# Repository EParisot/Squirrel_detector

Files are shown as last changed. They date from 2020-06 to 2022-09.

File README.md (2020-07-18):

# SQuareRooT Project
#### Capture wildlife from your garden !

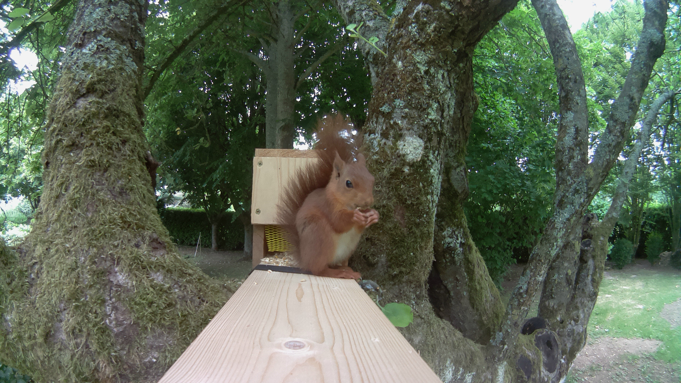
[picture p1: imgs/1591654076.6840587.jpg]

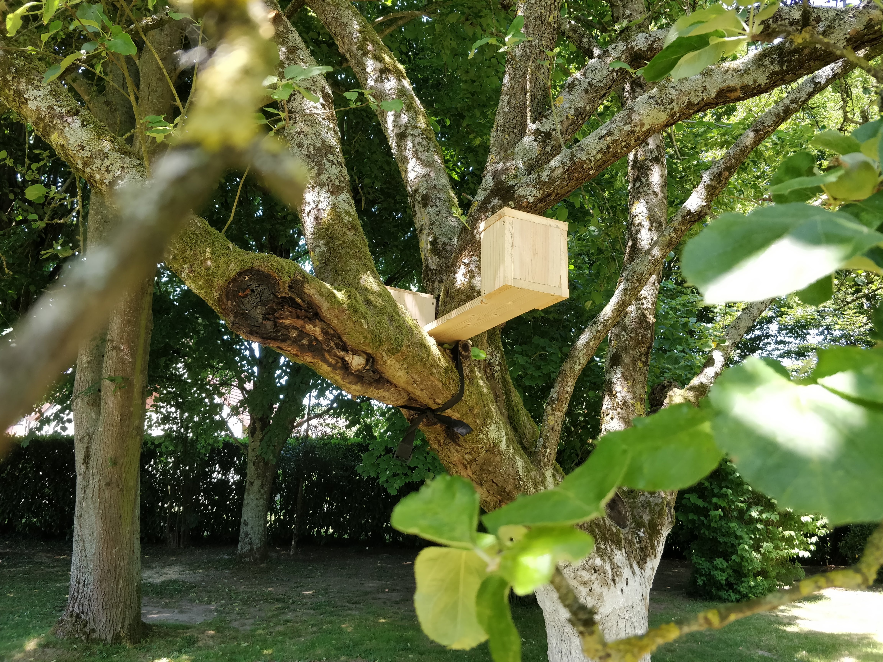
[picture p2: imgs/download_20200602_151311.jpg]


#### More pictures [HERE](https://photos.app.goo.gl/eW7Maa1WmrSnC65B8)

## Material:
* RaspberryPi + SD card : [Shop](https://www.amazon.fr/Raspberry-Pi-3-Mod%C3%A8le-B-Carte-m%C3%A8re/dp/B07BDR5PDW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)
(any RPi model will fit, maybe avoid using a RPi4 (overkill + heat))
* Camera : [Shop](https://www.amazon.fr/Raspberry-160%C2%B0Fisheye-Camera-Longruner-Adjustable-Focus/dp/B074W6TPHF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)
* ToF distance sensor : [Shop](https://www.amazon.fr/gp/product/B07RWT9D5Z/ref=ppx_yo_dt_b_asin_title_o07_s00?ie=UTF8&psc=1)
* Battery pack : [Shop](https://www.amazon.fr/gp/product/B07HK5VGB6/ref=ppx_yo_dt_b_asin_title_o00_s00?ie=UTF8&psc=1)
* Button [Shop](https://www.amazon.fr/AZDelivery-Interrupteur-capteur-dinterrupteur-Arduino/dp/B089QK4XLR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 )
* Light sensor [Shop](https://www.amazon.fr/Photor%C3%A9sistances-GL5539-30K-90K-d%C3%A9pendant-lumi%C3%A8re/dp/B01EZZMLOI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)
* Jumper cables, 1 Capacitor (1microf), 1 led, 1 resistor (330 ohms)

# Instructions:

Based on Raspberry Pi Zero W
Raspberry Pi OS (32-bit) Lite
Minimal image based on Debian Buster
Version:May 2020

### Wire Camera, distance sensor, button, led, everything !

scheme to come...

### Clone the repo on the RPi and install
```
sudo apt-get install git
git clone https://github.com/EParisot/Squirrel_detector.git ~/Squirrel_detector
cd ~/Squirrel_detector
sudo ./install.sh
```
(You will be asked for some interractions while setting wifi... stay focused !)

### Reboot, find a great spot and ... enjoy the show ! 

Everything is made to save up battery life: WIFI stay shutted down until you press the button (no picture can be taken during this time), HDMI is stopped on boot.

A camera test shot is made on start, everything is logged in activity.log file.

If the brightness is not sufficient, no sensor will be triggered for 10 min to avoid black images (and prevent useless power consumption)

A compagnon App is also in progress and will allow user to download images from the device. Start App, press the button and download your pictures on the phone.

## Usefull commands:
Start the STA (wifi client) mode :
```
sudo systemctl start wpa_supplicant@wlan0.service
```
Start the AP (wifi server) mode :
```
sudo systemctl start wpa_supplicant@ap0.service
```
Restart HDMI port :
```
sudo /usr/bin/tvservice -p
(-o to stop)
```

## Licensing
This project is under MIT license which means you can share, use, modify it if you cite the author (me)... Thanks !

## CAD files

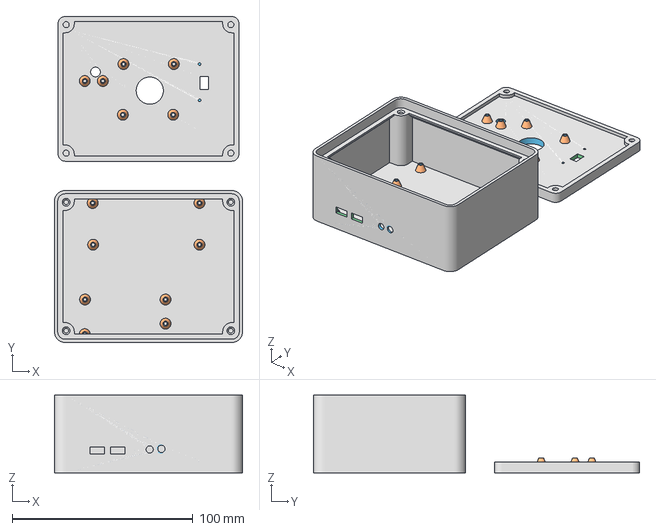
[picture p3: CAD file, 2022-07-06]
3Dprints/project_box_full.3mf
104.0 x 180.1 x 43.0 mm

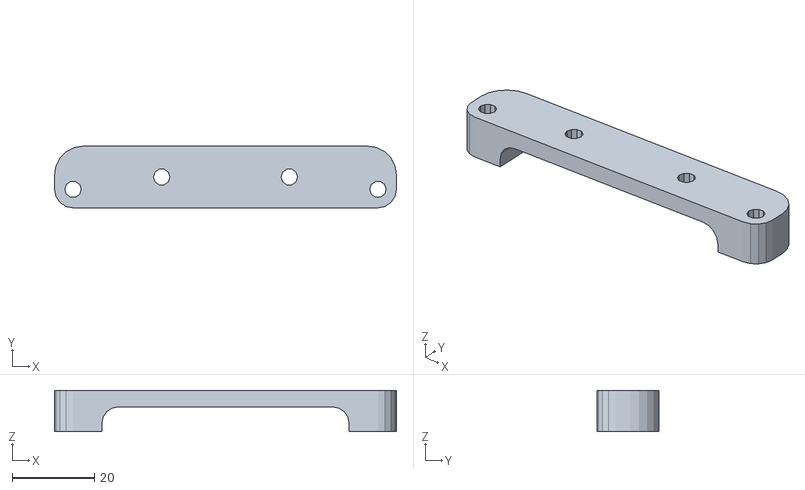
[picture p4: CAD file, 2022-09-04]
3Dprints/Porte_plaque_aimant_V2.stl
83.0 x 15.0 x 10.0

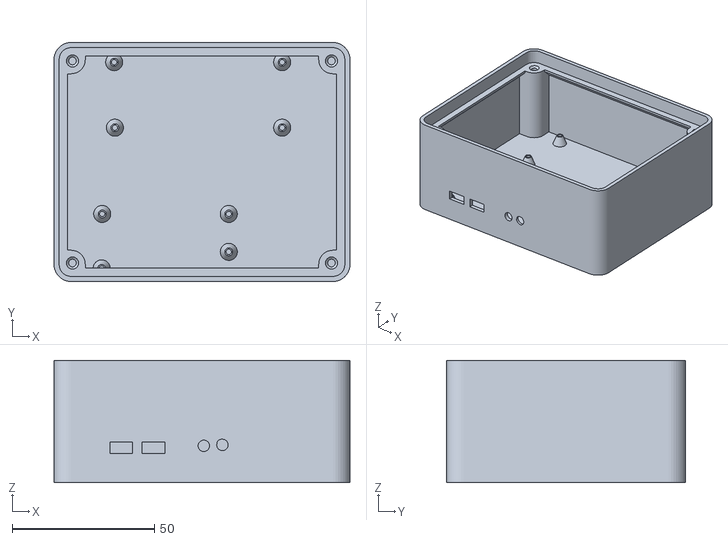
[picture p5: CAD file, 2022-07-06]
3Dprints/project_box_bottom.stl
104.0 x 84.0 x 43.0

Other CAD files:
3Dprints/project_box_full.stl

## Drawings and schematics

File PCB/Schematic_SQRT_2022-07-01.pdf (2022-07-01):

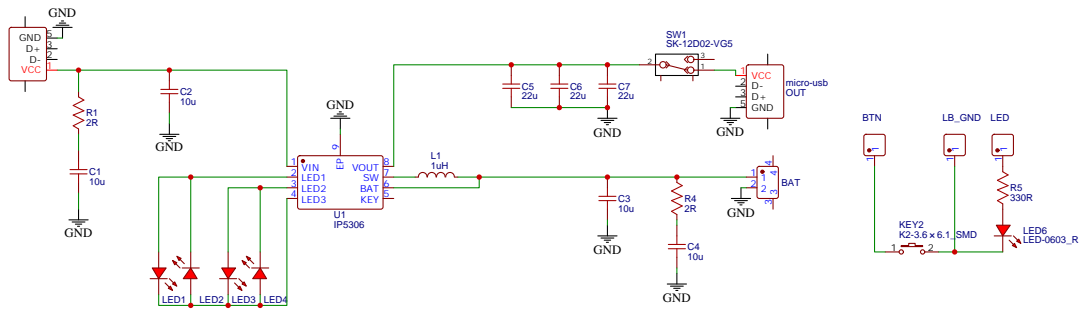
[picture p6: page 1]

Drawn By: parisot.eric.mail

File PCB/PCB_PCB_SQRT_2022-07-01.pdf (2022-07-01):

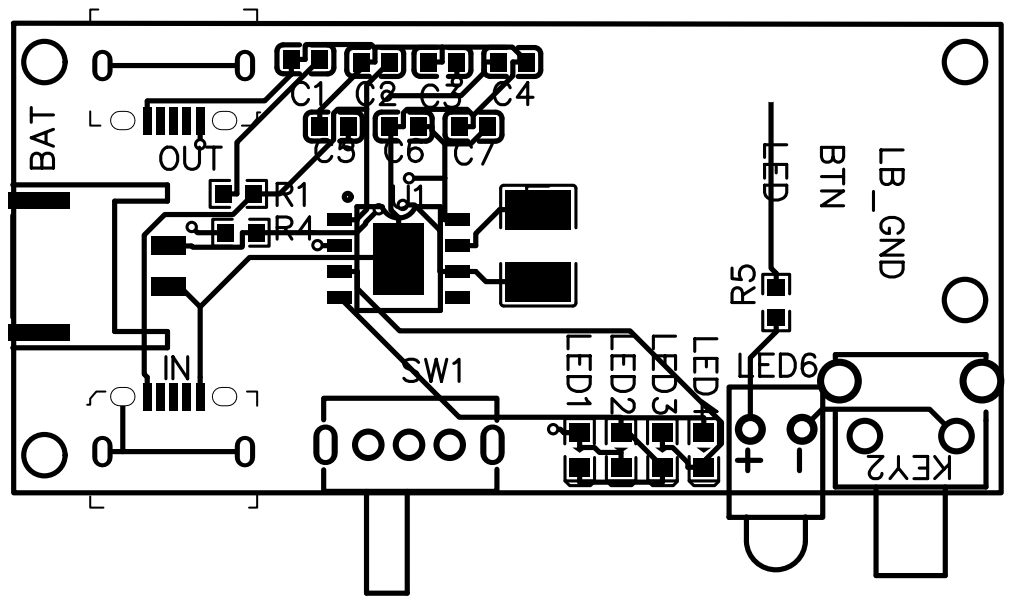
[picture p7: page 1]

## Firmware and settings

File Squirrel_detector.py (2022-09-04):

#! /usr/bin/python3
# coding: utf8
import os
import time
from picamera import PiCamera
import adafruit_vl53l0x
import board
import busio
import RPi.GPIO as GPIO

DEBUG = True

if DEBUG:
	import logging
	from logging.handlers import RotatingFileHandler

	logger = logging.getLogger("main_logger")
	logger.setLevel(logging.DEBUG)
	formatter = logging.Formatter('%(asctime)s :: %(levelname)s :: %(message)s')
	file_handler = RotatingFileHandler('activity.log', 'a', 1000000, 1)
	file_handler.setLevel(logging.DEBUG)
	file_handler.setFormatter(formatter)
	logger.addHandler(file_handler)
	stream_handler = logging.StreamHandler()
	stream_handler.setLevel(logging.DEBUG)
	logger.addHandler(stream_handler)

SRC_FOLDER = "/home/pi/Squirrel_detector/out/"
IMG_EXT = ".png"
WIFI = True
threshold = 45
BTN = 12
LED = 5
LIGHT = 24

def init_sensor():
	global threshold
	try:
		i2c = busio.I2C(board.SCL, board.SDA)
		sensor = adafruit_vl53l0x.VL53L0X(i2c)
		sensor.measurement_timing_budget = 200000
		thrs = []
		i = 5
		while i > 0:
			time.sleep(0.5)
			GPIO.output(LED, GPIO.HIGH)
			time.sleep(0.5)
			GPIO.output(LED, GPIO.LOW)
			distance = sensor.range // 10
			if DEBUG:
				logger.debug("distance = %d" % distance)
			if 0 < distance < 50:
				thrs.append(distance)
			i -= 1
		if len(thrs):
			new_thr = sum(thrs) // len(thrs)
			if 0 < new_thr <= 50:
				threshold = new_thr
		if DEBUG:
			logger.debug("threshold = %d" % threshold)
	except Exception as e:
		if DEBUG:
			logger.info("Error setting dist sensor %s" % str(e))
	return sensor

def init_GPIO():
	GPIO.setup(BTN, GPIO.IN, pull_up_down=GPIO.PUD_UP)
	GPIO.setup(LED, GPIO.OUT)
	GPIO.output(LED, GPIO.LOW)

def light_sensor():
	count = 0
	#Output on the pin for
	GPIO.setup(LIGHT, GPIO.OUT)
	GPIO.output(LIGHT, GPIO.LOW)
	time.sleep(0.1)
	#Change the pin back to input
	GPIO.setup(LIGHT, GPIO.IN)
	#Count until the pin goes high
	while (GPIO.input(LIGHT) == GPIO.LOW) and count <= 10000:
		count += 1
	return count

def clean_all():
	cmd = 'ifconfig wlan0 up'
	os.system(cmd)
	time.sleep(1)
	cmd = "systemctl start wpa_supplicant@ap0.service"
	GPIO.output(LED, GPIO.LOW)
	GPIO.cleanup()

def wifi_switch():
	global start_AP
	if WIFI == False:
		if DEBUG:
			logger.info("Disactivate Wifi AP")
		cmd = "systemctl start wpa_supplicant@wlan0.service"
		os.system(cmd)
		time.sleep(1)
		cmd = 'ifconfig wlan0 down'
		os.system(cmd)
	elif WIFI == True:
		if DEBUG:
			logger.info("Activate Wifi AP")
		cmd = 'ifconfig wlan0 up'
		os.system(cmd)
		time.sleep(1)
		cmd = "systemctl start wpa_supplicant@ap0.service"
		os.system(cmd)
		start_AP = time.time()
	time.sleep(1)

def button_callback(channel):
	if GPIO.input(BTN) == 0:
		global WIFI
		if DEBUG:
			logger.info("Button pushed ! Switching wifi state to %s" % ("OFF" if WIFI else "ON"))
		WIFI = not WIFI
		wifi_switch()

def take_snap():
	with PiCamera(resolution=(1920, 1080)) as camera:
		camera.rotation = 180
		filename = SRC_FOLDER + str(time.time()) + IMG_EXT
		if DEBUG:
			logger.info("captured %s" % filename)
		camera.capture(filename)

def test_snap():
	try:
		take_snap()
	except Exception as e:
		if DEBUG:
			logger.debug(str(e))
		clean_all()
		exit()
	GPIO.output(LED, GPIO.HIGH)
	time.sleep(3)
	GPIO.output(LED, GPIO.LOW)

if __name__ == "__main__":
	if DEBUG:
		logger.info("SQRT Started...")
	init_GPIO()
	sensor = init_sensor()
	WIFI = False
	start_AP = None
	wifi_switch()
	GPIO.add_event_detect(BTN, GPIO.FALLING, callback=button_callback, bouncetime=500)
	try:
		test_snap()
		while True:
			light = light_sensor()
			if DEBUG:
				logger.debug("Light level = %d" % light)
			if not WIFI and light > 10000:
				logger.info("Going to sleep for 10 min...")
				time.sleep(60 * 10)
				continue
			if WIFI == True:
				time.sleep(0.5)
				GPIO.output(LED, GPIO.HIGH)
				time.sleep(0.5)
				GPIO.output(LED, GPIO.LOW)
				if start_AP != None and time.time() - start_AP >= 60 * 15:
					start_AP = None
					WIFI = False
					wifi_switch()
				if DEBUG:
					distance = sensor.range // 10
					logger.debug("distance = %d" % distance)
			else:
				GPIO.output(LED, GPIO.LOW)
				time.sleep(1)
				distance = sensor.range // 10
				if DEBUG:
					logger.debug("distance = %d" % distance)
				if distance > 0 and distance < threshold:
					if DEBUG:
						logger.debug("SNAP")
					take_snap()
	except Exception as e:
		if DEBUG:
			logger.debug(str(e))
	clean_all()

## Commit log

2020-06-09 edited LEDS + README Signed-off-by: eparisot <eparisot@student.42.fr>
2020-07-07 filter kitkeep
2020-07-09 add button event
2020-07-09 test button
2020-07-09 change btn pin
2020-07-09 sensor init
2020-07-09 fix led
2020-07-09 stop main thread
2020-07-09 update led from main loop
2020-07-12 wird sudo boy
2020-07-13 i2c install
2020-07-13 light sensor
2020-07-14 fix ap stop set wifi locale and clear images
    [Squirrel_detector.py]
2020-07-14 switch wifi after 15min
2020-07-14 fix led on wifi stops auto
    [Squirrel_detector.py]
2020-07-18 fix light logs + start_AP to none if man stop
    [Squirrel_detector.py]
2020-07-20 add sleep time on button trigger
2021-07-14 try to avoid bouncing button
    [Squirrel_detector.py]
2021-07-19 led snap and btn bounce
    [Squirrel_detector.py]
2021-07-19 3D models Signed-off-by: eparisot <eparisot@student.42.fr>
    [project_box_full.3mf, project_box_full.stl]
2021-08-28 add box
    [project_box_bottom.stl, project_box_full.3mf, project_box_full.stl]
2022-07-01 update PCB
    [project_box_bottom.stl, project_box_full.3mf, project_box_full.stl]
2022-07-03 prints and light sensor
    [project_box_full.3mf, project_box_full.stl]
2022-07-06 sleep fix and 3D
    [project_box_bottom.stl, project_box_full.3mf, project_box_full.stl]
2022-09-04 add pull
    [Porte_plaque_aimant_V2.stl]
